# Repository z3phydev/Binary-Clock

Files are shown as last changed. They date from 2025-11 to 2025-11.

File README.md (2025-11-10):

# Binary Clock
## What is it?
A binary clock is a digital clock that displays the time using binary numbers instead of traditional digits. Each column represents a digit of time, so the first column is the Tens Dight of the hours, and every LED vertically is a number in binary format.
## Why did I make it?
I was originally inspired by seeing a software demo by the YouTube channel, Figuring Things Out. I wanted to try creating something similar but as a physical desk clock. The result is a clock that most people can't read but find cool. I like how the exposed PCB give it even more of that digital aesthetic.

## PCB


## PCB and Stand Render

Binary Clock

## Schematic



## BOM

|Reference |Qty|Value/Description|MFR |MFR No. |Mouser No. |Datasheet |Unit Price GBP|Total Price GBP|Note |FIELD11 |FIELD12 |FIELD13 |
|---|---|---|---|---|---|---|---|---|---|---|---|---|
|A1 |1  |Raspberry Pi Pico|Raspberry Pi |SC0915 |358-SC0915 |https://datasheets.raspberrypi.com/pico/pico-datasheet.pdf |4.8 |4.8 |If you want the headers you will need to buy elsewhere| | | |
|D1,D2,D3,D4,D5,D6,D7,D8,D9,D10,D11,D12,D13,D14,D15,D16,D17,D18,D19,D20 |20 |RED LED |Cree LED |C5SMF-RJF-CT0W0BB2 |941-C5SMFRJFCT0W0BB2|~ |0.116 |2.32 | | | | |
|J1 |1  |USB C |GCT |USB4085-GF-A |640-USB4085-GF-A |https://www.usb.org/sites/default/files/documents/usb_type-c.zip |0.643 |0.643 | | | | |
|Q1,Q2,Q3,Q4,Q5,Q6,Q7,Q8,Q9,Q10,Q11,Q12,Q13,Q14,Q15,Q16,Q17,Q18,Q19,Q20 |20 |NPN Transistor |onsemi / Fairchild|BC547BBU |512-BC547BBU |https://ngspice.sourceforge.io/docs/ngspice-html-manual/manual.xhtml#cha_BJTs|0.098 |1.96 | | | | |
|R1,R2 |2  |5.1kOhm Resistor |KOA Speer |MF1/4DCT52R5101F |660-MF1/4DCT52R5101F|~ |0.085 |0.17 | | | | |
|R3,R4,R5,R6,R7,R8,R9,R10,R11,R12,R13,R14,R15,R16,R17,R18,R19,R20,R21,R22 |20 |154Ohm Resistor  |Vishay / Beyschlag|MBA02040C1540FRP00 |594-MBA02040C1540FRP|~ |0.057 |1.14 | | | | |
|R23,R24,R25,R26,R27,R28,R29,R30,R31,R32,R33,R34,R35,R36,R37,R38,R39,R40,R41,R42|20 |1.18kOhm Resistor|YAGEO |MFR-25FRF52-1K18 |603-MFR-25FRF52-1K18|~ |0.029 |0.58 | | | | |
|SW1 |1  |Button |Same Sky |TS02-66-70-BK-260-LCR-D|179-TS026670BK260LCR|~ |0.73 |0.7 | | | | |
|U1 |1  |DS3231 RTC Module|WINGONEER |ASIN : B01H5NAFUY | |http://datasheets.maximintegrated.com/en/ds/DS3231.pdf |3.99 |3.99 |Amazon link : https://amzn.eu/d/fGpd2tB | | | |
| | | | | | | | | | | |Total Price USD approx|Total Price GBP|
| | | | | | | | | | |Items |15.06 |11.51 |
| | | | | | | | | | |Shipping|20.28 |15.5 |
| | | | | | | | | | |Finnal  |35.34 |27.01 |

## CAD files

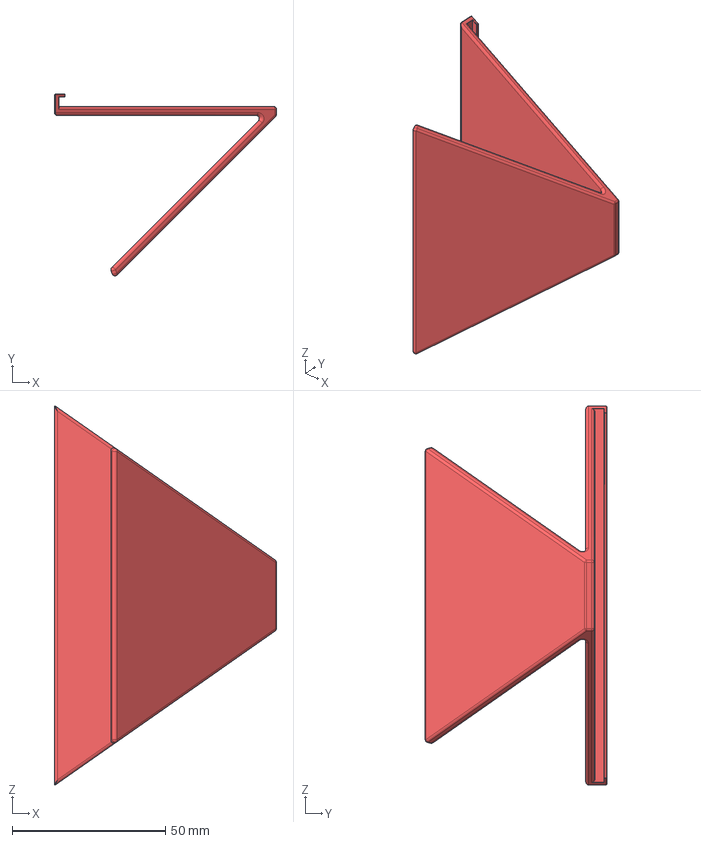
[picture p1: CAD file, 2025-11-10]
3D Models/Step/Stand.stp
72.5 x 59.3 x 123.7 mm

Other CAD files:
3D Models/Source/Binary Clock.iam

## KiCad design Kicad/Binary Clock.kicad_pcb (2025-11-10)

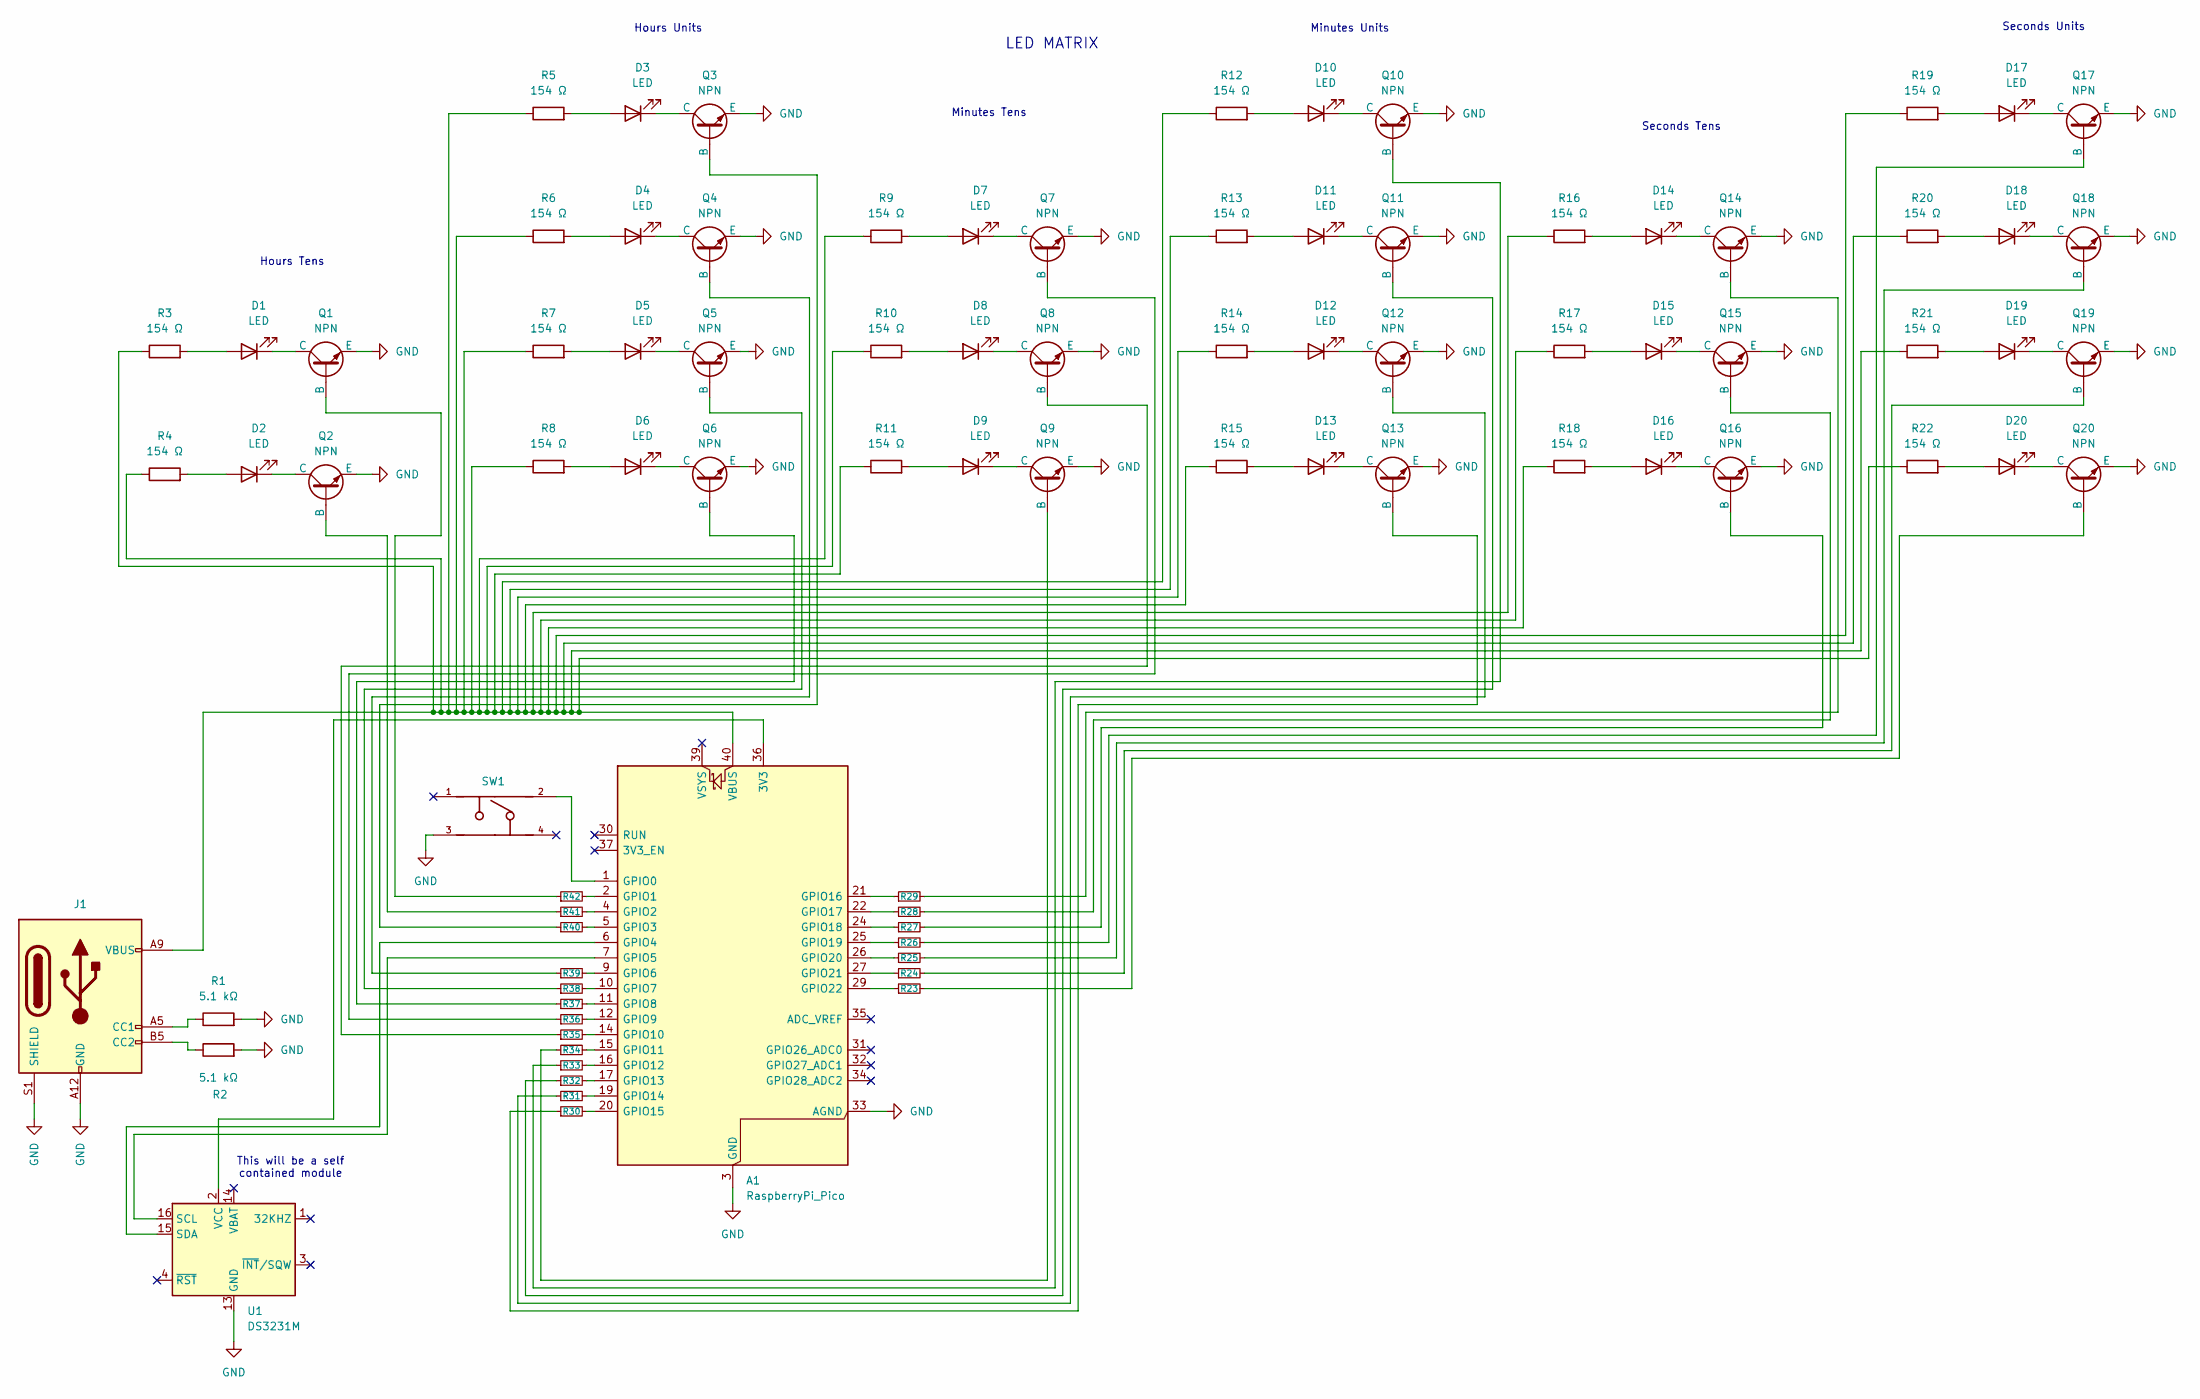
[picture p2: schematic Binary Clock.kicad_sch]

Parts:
A1: RaspberryPi_Pico; RaspberryPi_Pico_Common_THT
D1, D2, D3, D4, D5, D6, D7, D8, D9, D10, D11, D12, D13, D14, D15, D16, D17, D18, D19, D20: LED; LED_D5.0mm
J1: USB_C_PowerOnly; GCT_USB4085-GF-A_REVA4
Q1, Q2, Q3, Q4, Q5, Q6, Q7, Q8, Q9, Q10, Q11, Q12, Q13, Q14, Q15, Q16, Q17, Q18, Q19, Q20: NPN; TO92127P476H533-3
R1, R2: 5.1 kΩ; R_Axial_DIN0207_L6.3mm_D2.5mm_P7.62mm_Horizontal
R3, R4, R5, R6, R7, R8, R9, R10, R11, R12, R13, R14, R15, R16, R17, R18, R19, R20, R21, R22: 154 Ω; R_Axial_DIN0207_L6.3mm_D2.5mm_P7.62mm_Horizontal
R23, R24, R25, R26, R27, R28, R29, R30, R31, R32, R33, R34, R35, R36, R37, R38, R39, R40, R41, R42: R_Small; R1.18
SW1: TS02-66-70-BK-260-LCR-D; SW_TS02-66-70-BK-260-LCR-D; PARTREV 1.0
U1: DS3231M; Untitled

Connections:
GND: A1.3 (GND), A1.8 (GND), A1.13 (GND), A1.18 (GND), A1.23 (GND), A1.28 (GND), A1.33 (AGND), A1.38 (GND), J1.A12 (GND), J1.B12 (GND), J1.S1 (SHIELD), Q1.3 (E), Q2.3 (E), Q3.3 (E), Q4.3 (E), Q5.3 (E), Q6.3 (E), Q7.3 (E), Q8.3 (E), Q9.3 (E), Q10.3 (E), Q11.3 (E), Q12.3 (E), Q13.3 (E), Q14.3 (E), Q15.3 (E), Q16.3 (E), Q17.3 (E), Q18.3 (E), Q19.3 (E), Q20.3 (E), R1.2, R2.2, SW1.3, U1.5 (GND), U1.6 (GND), U1.7 (GND), U1.8 (GND), U1.9 (GND), U1.10 (GND), U1.11 (GND), U1.12 (GND), U1.13 (GND)
unnamed: A1.36 (3V3), U1.2 (VCC)
unnamed: A1.1 (GPIO0), SW1.2
unnamed: A1.2 (GPIO1), R42.2
unnamed: A1.4 (GPIO2), R41.2
unnamed: A1.5 (GPIO3), R40.2
unnamed: A1.6 (GPIO4), U1.15 (SDA)
unnamed: A1.7 (GPIO5), U1.16 (SCL)
unnamed: A1.9 (GPIO6), R39.2
unnamed: A1.10 (GPIO7), R38.2
unnamed: A1.11 (GPIO8), R37.2
unnamed: A1.12 (GPIO9), R36.2
unnamed: A1.14 (GPIO10), R35.2
unnamed: A1.15 (GPIO11), R34.2
unnamed: A1.16 (GPIO12), R33.2
unnamed: A1.17 (GPIO13), R32.2
unnamed: A1.19 (GPIO14), R31.2
unnamed: A1.20 (GPIO15), R30.2
unnamed: A1.21 (GPIO16), R29.1
unnamed: A1.22 (GPIO17), R28.1
unnamed: A1.24 (GPIO18), R27.1
unnamed: A1.25 (GPIO19), R26.1
unnamed: A1.26 (GPIO20), R25.1
unnamed: A1.27 (GPIO21), R24.1
unnamed: A1.29 (GPIO22), R23.1
unnamed: A1.40 (VBUS), J1.A9 (VBUS), J1.B9 (VBUS), R3.1, R4.1, R5.1, R6.1, R7.1, R8.1, R9.1, R10.1, R11.1, R12.1, R13.1, R14.1, R15.1, R16.1, R17.1, R18.1, R19.1, R20.1, R21.1, R22.1
unnamed: D1.2 (A), R3.2
unnamed: D1.1 (K), Q1.1 (C)
unnamed: D2.2 (A), R4.2
unnamed: D2.1 (K), Q2.1 (C)
unnamed: D3.2 (A), R5.2
unnamed: D3.1 (K), Q3.1 (C)
unnamed: D4.2 (A), R6.2
unnamed: D4.1 (K), Q4.1 (C)
unnamed: D5.2 (A), R7.2
unnamed: D5.1 (K), Q5.1 (C)
unnamed: D6.2 (A), R8.2
unnamed: D6.1 (K), Q6.1 (C)
unnamed: D7.2 (A), R9.2
unnamed: D7.1 (K), Q7.1 (C)
unnamed: D8.2 (A), R10.2
unnamed: D8.1 (K), Q8.1 (C)
unnamed: D9.2 (A), R11.2
unnamed: D9.1 (K), Q9.1 (C)
unnamed: D10.2 (A), R12.2
unnamed: D10.1 (K), Q10.1 (C)
unnamed: D11.2 (A), R13.2
unnamed: D11.1 (K), Q11.1 (C)
unnamed: D12.2 (A), R14.2
unnamed: D12.1 (K), Q12.1 (C)
unnamed: D13.2 (A), R15.2
unnamed: D13.1 (K), Q13.1 (C)
unnamed: D14.2 (A), R16.2
unnamed: D14.1 (K), Q14.1 (C)
unnamed: D15.2 (A), R17.2
unnamed: D15.1 (K), Q15.1 (C)
unnamed: D16.2 (A), R18.2
unnamed: D16.1 (K), Q16.1 (C)
unnamed: D17.2 (A), R19.2
unnamed: D17.1 (K), Q17.1 (C)
unnamed: D18.2 (A), R20.2
unnamed: D18.1 (K), Q18.1 (C)
unnamed: D19.2 (A), R21.2
unnamed: D19.1 (K), Q19.1 (C)
unnamed: D20.2 (A), R22.2
unnamed: D20.1 (K), Q20.1 (C)
unnamed: J1.A5 (CC1), R1.1
unnamed: J1.B5 (CC2), R2.1
unnamed: Q1.2 (B), R42.1
unnamed: Q2.2 (B), R41.1
unnamed: Q3.2 (B), R40.1
unnamed: Q4.2 (B), R39.1
unnamed: Q5.2 (B), R38.1
unnamed: Q6.2 (B), R37.1
unnamed: Q7.2 (B), R36.1
unnamed: Q8.2 (B), R35.1
unnamed: Q9.2 (B), R34.1
unnamed: Q10.2 (B), R33.1
unnamed: Q11.2 (B), R32.1
unnamed: Q12.2 (B), R31.1
unnamed: Q13.2 (B), R30.1
unnamed: Q14.2 (B), R29.2
unnamed: Q15.2 (B), R28.2
unnamed: Q16.2 (B), R27.2
unnamed: Q17.2 (B), R26.2
unnamed: Q18.2 (B), R25.2
unnamed: Q19.2 (B), R24.2
unnamed: Q20.2 (B), R23.2

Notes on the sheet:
This will be a self contained module
Hours Tens
Seconds Units
LED MATRIX
Minutes Units
Minutes Tens
Seconds Tens
Hours Units

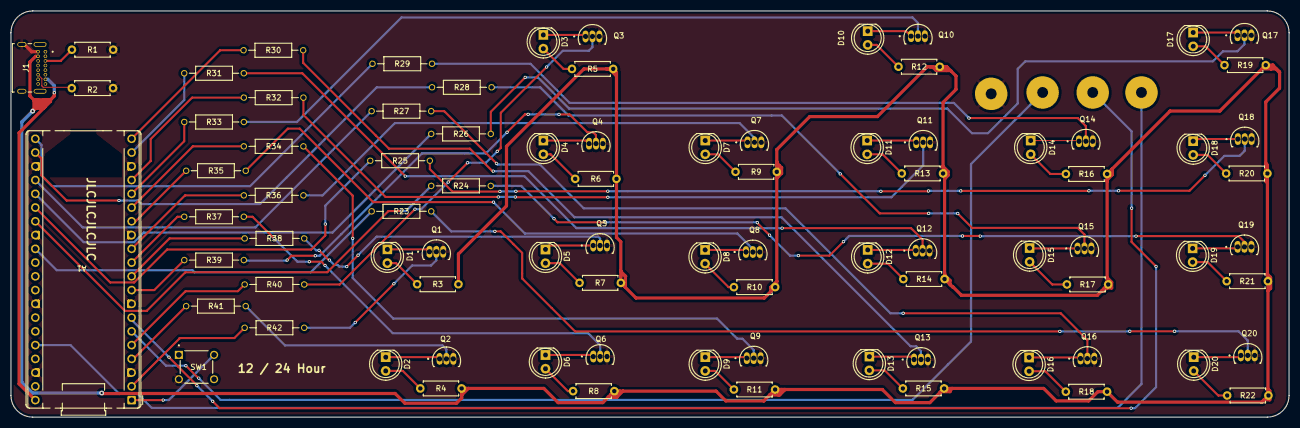
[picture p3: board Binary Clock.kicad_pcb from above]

Board: 4 copper layers, 236.0 x 75.0 mm, 86 parts (1 on the bottom side), 88 nets.

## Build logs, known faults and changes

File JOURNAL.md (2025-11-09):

<!--
  ===================    !!READ THIS NOTICE!!   ====================
  DO NOT edit this file manually. Your changes WILL BE OVERWRITTEN!
  This journal is auto generated and updated by Hack Club Blueprint.
  To edit this file, please edit your journal entries on Blueprint.
  ==================================================================
-->

## 11/6/2025 7 PM - Started the Schmatic - Time Spent Little under 2 Hours  

I begun the schematic. A pico and RTC will be the heart of this, gpio pins will contorl transistors to allow the correct leds to light up. An rtc module will contorl the time. I've still to connect the leds and transistors. I will soon start to have too think about the actual components to allow right current and voltage ect.    

## 11/6/2025 9 PM - All thats left to do is resistors - Time Spent 2.4 Hours  

Finished connecting all the LEDs and transistors, Yet to add the restiance for the resistors from the power and yet to pun any restiors on the gpio lines. 

## 11/7/2025 - Finished the Schematic - Time Spent 3 Hours  

Finished the Schematic. All the components and wires in place. All the resitors now have values. And picked out all my componets from Mouser, still need to do the BOM but I've got them all so that should be easy. 

## 11/8/2025 11 AM - V1 of BOM complete - Time Spent Little under an Hour  

Got all the parts selected and made a [BOM](/user-attachments/blobs/proxy/eyJfcmFpbHMiOnsiZGF0YSI6OTM2MSwicHVyIjoiYmxvYl9pZCJ9fQ==--e1ad649c08b2cf2d86da2a36774f975a52a059b6/BOM.csv). Almost all componets are from Mouser with the only non Mouser part being the RTC Breakout board (from Amazon). 

## 11/8/2025 7 PM - 75% through the PCB - Time Spent Almost 4 Hours  

Almost done desgining, got down the layout, started the routing process. The PCB will be roughly 24cm x 8 cm in size. IDK why it took soo long to get here. I think I might print a stand for it! 

## 11/9/2025 4 PM - Finished desgining the PCB - Time Spent 3.3 Hours  

Finnished the pcb, all parts routed, all parts placed. This took way longer than I thought it would as usall, you never really think about it till you start logging it. Just now to get all the requirements and then finnally ship it! 

## 11/9/2025 6 PM - Stand - Time Spent 25 Min  

After thinking some thoughts I quickly made up a litte stand for the pcb. I will probally end up making somthing similar out of bent acylic, this mostly just a quick visaulisation.  

## 11/9/2025 7 PM - Time Logged 15.7 Hours  

If you count the amount of reasearch and time spent think it would be a whole lot more. All I'm doing now if filling out the guildlines and then time to ship!         Also It said put your total time up top but the md says not to edit it so just doing here then ig.

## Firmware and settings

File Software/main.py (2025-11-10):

from machine import Pin, I2C
import utime

class DS3231:
    def __init__(self, i2c, addr=0x68):
        self.i2c = i2c
        self.addr = addr
    def bcd2dec(self, b):
        return (b >> 4) * 10 + (b & 0x0F)
    def read_time(self):
        data = self.i2c.readfrom_mem(self.addr, 0x00, 7)
        s = self.bcd2dec(data[0])
        m = self.bcd2dec(data[1])
        h = self.bcd2dec(data[2] & 0x3F)
        return h, m, s

i2c = I2C(0, scl=Pin(5), sda=Pin(4))
rtc = DS3231(i2c)

led_map = {
    "h10": [Pin(2, Pin.OUT), Pin(1, Pin.OUT)],
    "h1":  [Pin(8, Pin.OUT), Pin(7, Pin.OUT), Pin(6, Pin.OUT), Pin(3, Pin.OUT)],
    "m10": [Pin(11, Pin.OUT), Pin(10, Pin.OUT), Pin(9, Pin.OUT)],
    "m1":  [Pin(15, Pin.OUT), Pin(14, Pin.OUT), Pin(13, Pin.OUT), Pin(12, Pin.OUT)],
    "s10": [Pin(18, Pin.OUT), Pin(17, Pin.OUT), Pin(16, Pin.OUT)],
    "s1":  [Pin(22, Pin.OUT), Pin(21, Pin.OUT), Pin(20, Pin.OUT), Pin(19, Pin.OUT)],
}

def show_binary(value, pins):
    for i, p in enumerate(pins):
        p.value((value >> i) & 1)

def get_hour_12_24(hour, use_24):
    if use_24:
        return hour
    h12 = hour % 12
    return 12 if h12 == 0 else h12

switch = Pin(0, Pin.IN, Pin.PULL_UP)
use_24 = True
last_state = 1

while True:
    state = switch.value()
    if state == 0 and last_state == 1:
        use_24 = not use_24
        utime.sleep(0.2)
    last_state = state

    h, m, s = rtc.read_time()
    h = get_hour_12_24(h, use_24)

    show_binary(h // 10, led_map["h10"])
    show_binary(h % 10, led_map["h1"])
    show_binary(m // 10, led_map["m10"])
    show_binary(m % 10, led_map["m1"])
    show_binary(s // 10, led_map["s10"])
    show_binary(s % 10, led_map["s1"])

    utime.sleep(0.2)

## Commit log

2025-11-08 V1 of BOM
    [BOM.csv]
2025-11-09 Better BOM
    [BOM.csv]
2025-11-09 PCB step assembly
2025-11-09 Source files
    [Binary Clock.iam]
2025-11-09 Kicad files
    [Binary Clock.kicad_pcb, Binary Clock.kicad_sch]
2025-11-10 Create BOM
2025-11-10 Added Render
    Added a new image of the Binary Clock to the PCB and Stand Render section.
